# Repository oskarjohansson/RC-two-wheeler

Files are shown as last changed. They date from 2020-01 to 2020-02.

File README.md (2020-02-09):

# RC two wheeler
A 4 kW RC car with overkill BLDC motors and two VESCs and a 5 kW LiPo.  

## Hardware
- Flipsky VESC v4.12 x 2
- KEDA 63-64 190KV 2kW x 2
- Arduino Nano x2
- nRF24 x2
- 3S 60C 4000 mAh Turnigy Heavy duty LiPo
- Joystick 
- ~~2P2S N.E.S.E module x 2~~
- ~~Samsung 25E á 20A x 8~~
- ~~FrSky transmitter~~
- ~~RF Reciever~~

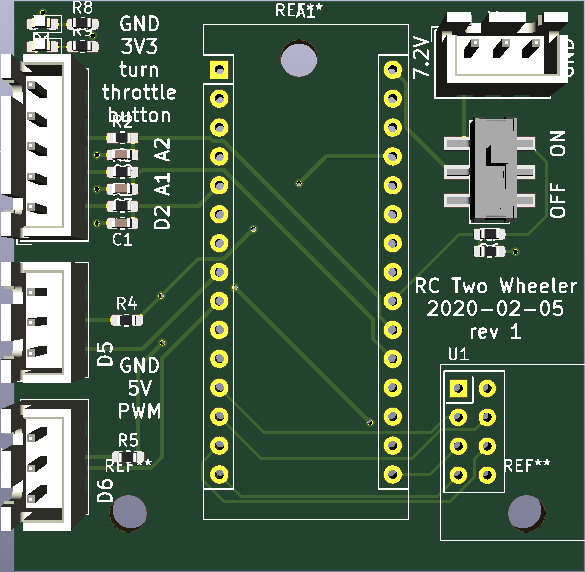
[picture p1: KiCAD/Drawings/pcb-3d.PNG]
PCB in 3D Rev 1 2020-02-09


### PCB
- PWM/5V/GND in
- Nano
- nRF24 
- ON/OFF
- Battery
- Joystick  

## Software
- VESC Tool v0.95. 
- VSCode project for Nano.

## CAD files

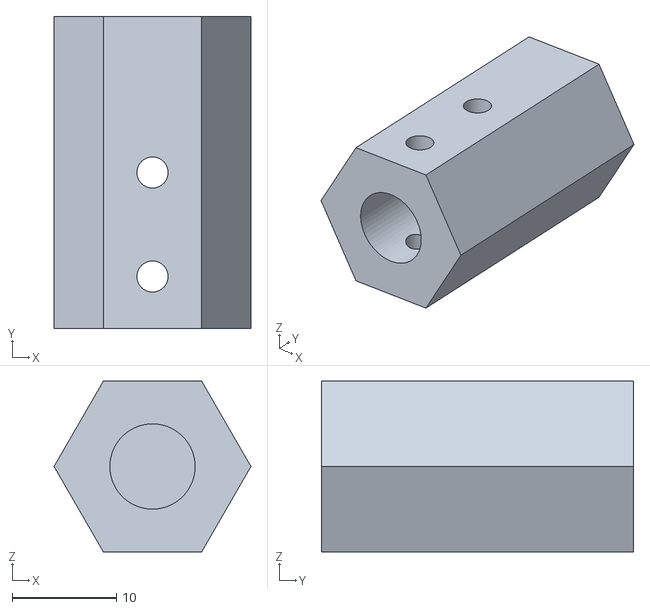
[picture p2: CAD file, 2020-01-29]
CAD/WheelInner.stl
18.9 x 30.0 x 16.4

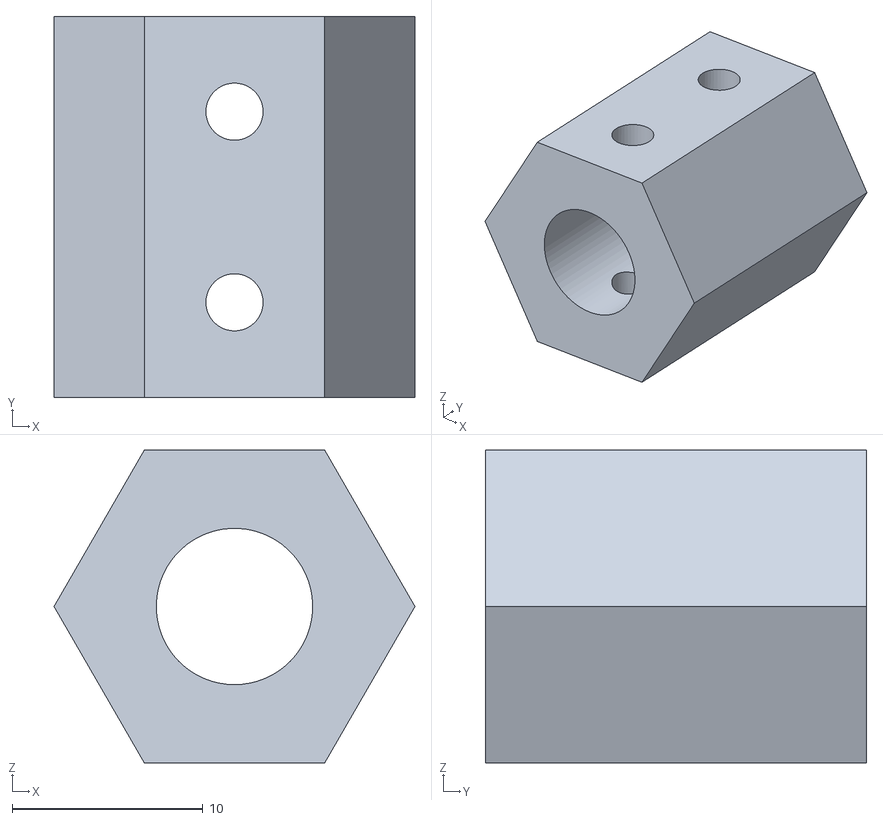
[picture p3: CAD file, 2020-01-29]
CAD/Wheel2.stl
18.9 x 20.0 x 16.4

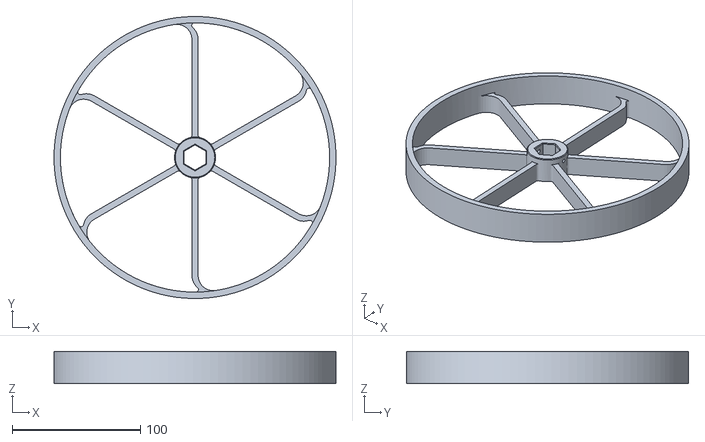
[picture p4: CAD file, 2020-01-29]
CAD/WheelOuter.stl
220.0 x 220.0 x 25.0

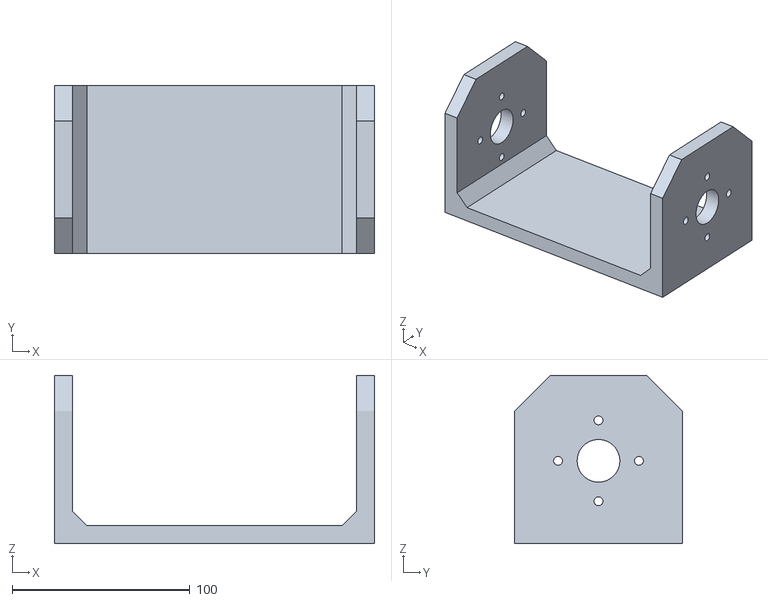
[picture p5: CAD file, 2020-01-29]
CAD/Platform.stl
180.0 x 94.5 x 94.5

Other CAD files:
CAD/Battery.ipt
CAD/KEDA_6364.ipt
CAD/NESE 2S2P.ipt
CAD/Platform.ipt
CAD/Platform.newVer.ipt
CAD/RC Assembly.iam
CAD/Wheel.ipt
CAD/Wheel2.ipt

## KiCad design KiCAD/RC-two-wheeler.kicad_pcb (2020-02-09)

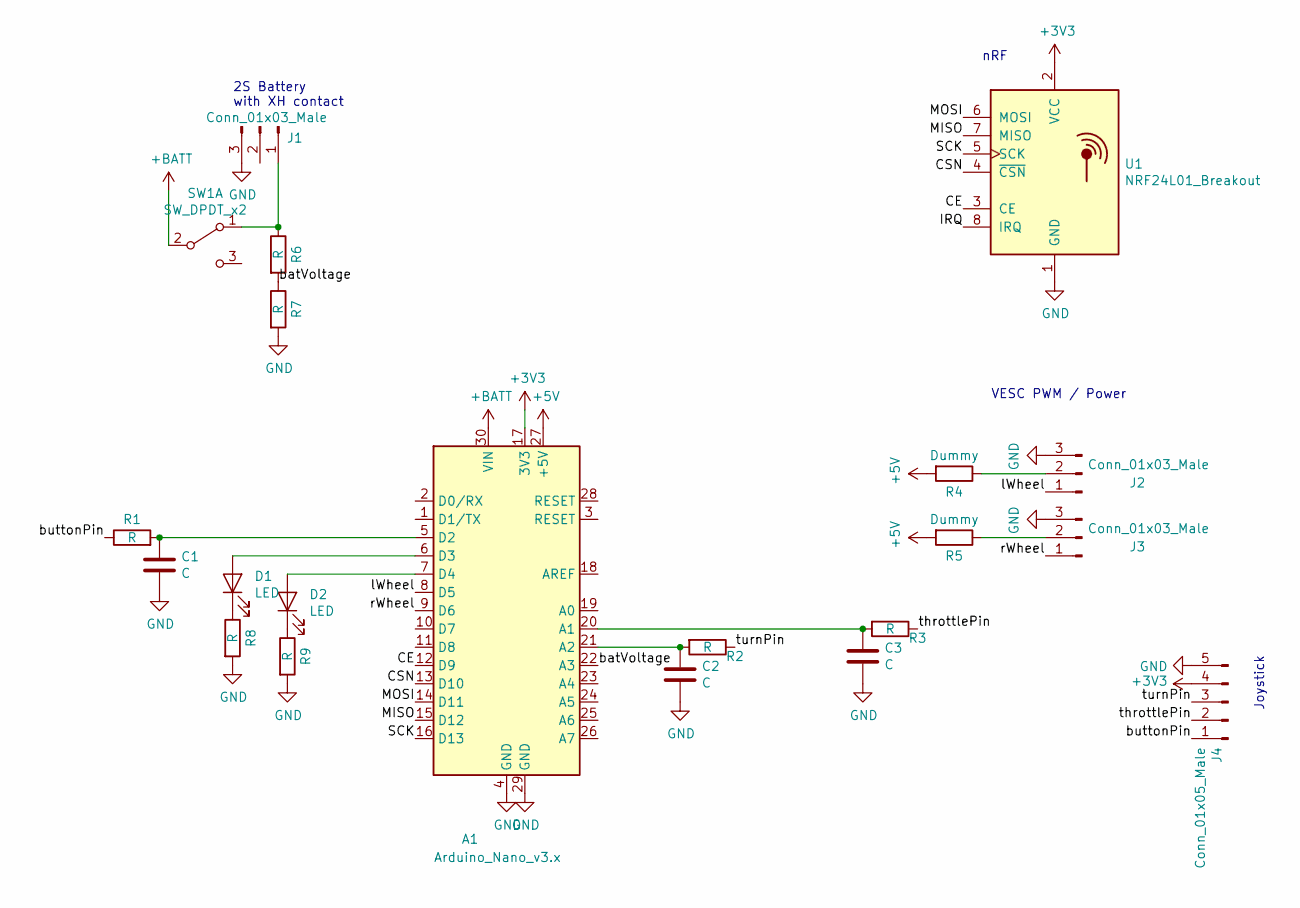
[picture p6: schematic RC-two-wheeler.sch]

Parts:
A1: Arduino_Nano_v3.x; Arduino_Nano
C1, C2, C3: C; C_0603_1608Metric_Pad1.05x0.95mm_HandSolder
D1, D2: LED; LED_0603_1608Metric_Pad1.05x0.95mm_HandSolder
J1, J2, J3: Conn_01x03_Male; JST_XH_B3B-XH-A_1x03_P2.50mm_Vertical
J4: Conn_01x05_Male; JST_XH_B5B-XH-A_1x05_P2.50mm_Vertical
R1, R2, R3, R6, R7, R8, R9: R; R_0603_1608Metric_Pad1.05x0.95mm_HandSolder
R4, R5: Dummy; R_0603_1608Metric_Pad1.05x0.95mm_HandSolder
SW1: SW_DPDT_x2; JS202011SCQN
U1: NRF24L01_Breakout; nRF24L01_Breakout

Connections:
+3V3: A1.17 (3V3), J4.4, U1.2 (VCC)
+5V: A1.27 (+5V), R4.2, R5.2
+BATT: A1.30 (VIN), SW1.2 (B)
/CE: A1.12 (D9), U1.3 (CE)
/CSN: A1.13 (D10), U1.4 (~CSN)
/IRQ: U1.8 (IRQ)
/MISO: A1.15 (D12), U1.7 (MISO)
/MOSI: A1.14 (D11), U1.6 (MOSI)
/SCK: A1.16 (D13), U1.5 (SCK)
/batVoltage: A1.22 (A3), R6.2, R7.1
/buttonPin: J4.1, R1.1
/lWheel: A1.8 (D5), J2.1
/rWheel: A1.9 (D6), J3.1
/throttlePin: J4.2, R3.1
/turnPin: J4.3, R2.1
GND: A1.4 (GND), A1.29 (GND), C1.2, C2.2, C3.2, J1.3, J2.3, J3.3, J4.5, R7.2, R8.2, R9.2, U1.1 (GND)
unnamed: A1.5 (D2), C1.1, R1.2
unnamed: A1.6 (D3), D1.2 (A)
unnamed: A1.7 (D4), D2.2 (A)
unnamed: A1.20 (A1), C3.1, R3.2
unnamed: A1.21 (A2), C2.1, R2.2
unnamed: D1.1 (K), R8.1
unnamed: D2.1 (K), R9.1
unnamed: J1.1, R6.1, SW1.1 (A)
unnamed: J2.2, R4.1
unnamed: J3.2, R5.1

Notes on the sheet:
VESC PWM / Power
Joystick
2S Battery with XH contact
nRF

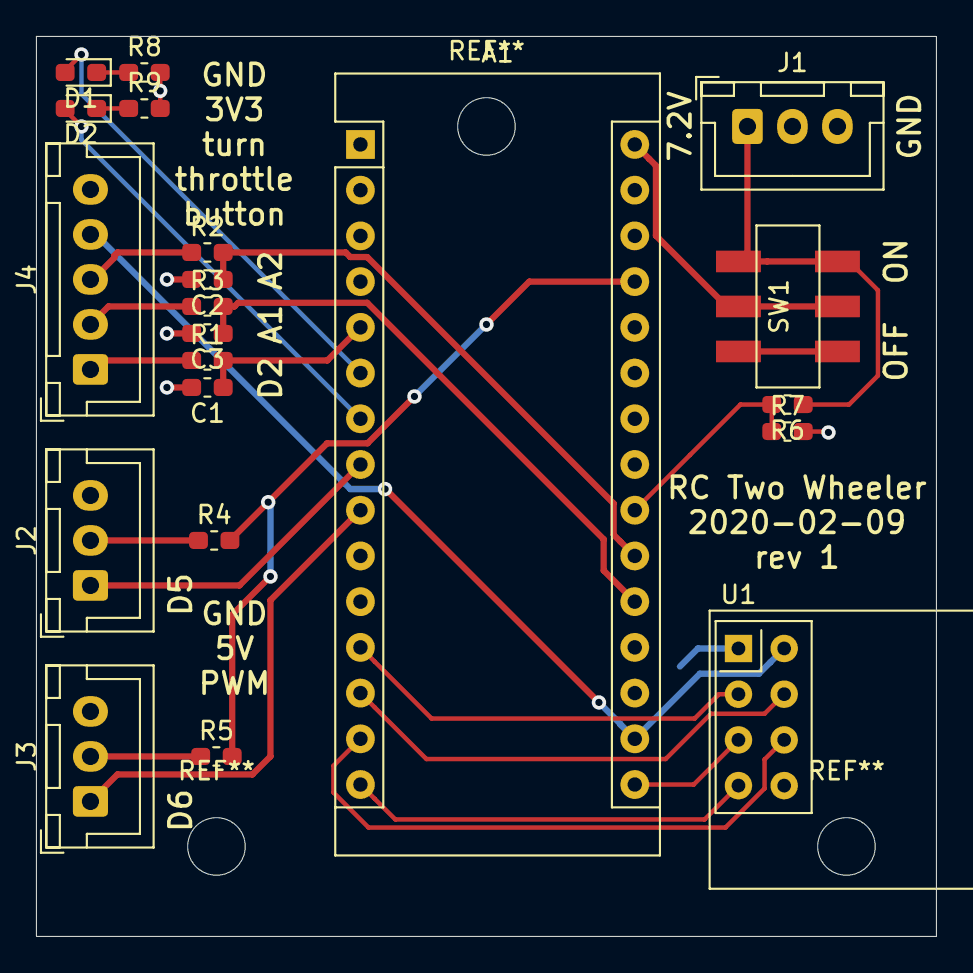
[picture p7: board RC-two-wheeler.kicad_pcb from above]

Board: 2 copper layers, 50.0 x 50.0 mm, 21 parts (0 on the bottom side), 25 nets.

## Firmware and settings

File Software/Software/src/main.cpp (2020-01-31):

/**
 * @file main.cpp
 * @author Oskar Johansson (oskar@irisnet.se)
 * @brief This project is to work with 2 MCU and 2 nRF24 to communicate throttle and turn. Based on 
 *        https://github.com/caselabbet/case-rc-car by Isak Åslund. 
 * @version 0.1
 * @date 2020-01-29 
 */
#include <Arduino.h>
#include <SoftwareSerial.h>
#include <Servo.h>
#include <RF24.h>


// Choose which to compile for 
#define reciever
//#define transmitter 
#define DEBUG

/**
 * To reuse same code for reciever and trasmitter 
 */


/**
 * Pin definition, same for reciever as transmitter
 */
#define lWheelPin 5
#define rWheelPin 6
#define throttlePin A1
#define turnPin A2
#define CE 9 
#define CSN 10

RF24 radio(CE,CSN); 
const byte address[6] = "00010";    // Adress for communicating
unsigned long lastData = 0;         // Used for knowing if data has been received recently
unsigned long lasttime = millis();  // To track of how long time since last transmitt / recieve 
int throttleComp = 0; 
int turnComp = 0;
bool setupOk = false; 
/**
 * A struct to store the recieved 
 * throttle and turn  
 */
typedef struct{
    int throttle;
    int turn;
}message_t;                         // Struct for making sending/receiving easy
message_t msg;
message_t analog; 
/**
 * Create the wheels 
 */
Servo lWheel, rWheel;

#define NOSPEED 90            // In servo degree
#define DEFAULTSPEED 20       // In servo degree
#define MAXSPEED 45           // In servo degree
#define MAXTURN 20            // In servo degree 
#define MAX_TIMEOUT 500       // in ms


/**
 * @brief Reciever:   Write the throttle and turn to the 
 *                    left and right wheel. Also checks
 *                    if the input values are to high/low. 
 *                    A turn is simply throttle+-turn on
 *                    this two-wheeler. 
 * 
 * @param throttle  - The throttle 0 - 180 
 * @param turn      - The turn 0 - 180
 */
void writeToWheels(int throttle, int turn) {
  int lSpeed = NOSPEED; int rSpeed = NOSPEED; 
  // 0 is max, 90 is still, 180 max reverse
  if(throttle < MAXSPEED)
    throttle = MAXSPEED; 
  else if (throttle > (MAXSPEED+90))
    throttle = MAXSPEED+90; 
  
  // Check so the turn speed isn't to fast 
  if(turn < MAXTURN)
    turn = MAXTURN;
  else if (turn > MAXTURN+90)
    turn = MAXTURN + 90; 
  // 
  turn -= 90; 
  // To check if it wasn't to long ago the input was recieved 
  if((millis() - lasttime)< MAX_TIMEOUT) {
    lSpeed = throttle+turn/2; 
    rSpeed = throttle-turn/2; 
  }
  
  // Write to output
  lWheel.write(lSpeed);
  rWheel.write(rSpeed);
  
  #ifdef DEBUG
      Serial.print("Input throttle: "); Serial.print(throttle); Serial.print("\t input turn: "); Serial.println(turn);
      Serial.print("Left output: "); Serial.print(lSpeed); Serial.print("\t \t Right output: "); Serial.println(rSpeed);
  #endif 
}

/**
 * @brief Transmitter:  Convert analog in signal to a throttle
 *                      level and write to nRF. 
 * 
 * @return true   - If successful transmitt
 * @return false  - If fail in writing to nRF
 */
bool writeToRadio() {
    // Convert to a servo signal (0 - 180 degrees) 90 is still, 0 max, 180 max
    msg.throttle = analog.throttle * 180.0 / 1024.0; 
    msg.turn = analog.turn * 180.0 / 1024.0; 
    bool succ = radio.write(&msg,sizeof(msg));
    #ifdef DEBUG
      Serial.print("Sent throttle: "); Serial.print(msg.throttle); Serial.print("\t sent turn: "); Serial.print(msg.turn); Serial.print(" successful transmitt: "); Serial.println(succ);
    #endif 
    return succ; 
}

/**
 * @brief Transmitter:  Write to nRF the throttle and turn. 
 *        Reciever:     Write the input from nRF to servo.  
 */
void writeOutput() {
  #ifdef transmitter
    writeToRadio(); 
  #else 
      writeToWheels(msg.throttle, msg.turn); 
  #endif
}


/**
 * @brief Transmitter:  Reads the analog value from joystick.
 *        Reciever:     See if new data available on nRF and 
 *                      save it to msg.  
 */
void readInput() {
  #ifdef transmitter 
    // Read the analog input with a simple LP filter
    analog.throttle = (analog.throttle + (analogRead(throttlePin)+throttleComp))/2;
    analog.turn = (analog.turn + (analogRead(turnPin)+turnComp))/2;
    #ifdef DEBUG
      Serial.print("Read throttle: "); Serial.print(analog.throttle); Serial.print("\t read turn: "); Serial.println(analog.turn);
    #endif 
  #else
    #ifdef DEBUG
      Serial.print("Radio available: "); Serial.println(radio.available());
    #endif 
    if(radio.available()) {
      radio.read(&msg, sizeof(msg)); 
      lasttime = millis(); 
      #ifdef DEBUG
        Serial.println("Recieved new input!");
      #endif
    } 
  #endif
}


/**
 * @brief Setup module as transmitter and sets analog input from joystick. 
 *        Also compensate for joystick value. Sets current value as new 0. 
 * 
 * @return true  - If able to connect setup nRF module
 * @return false - If unable to connect and setup nRf module
 */
bool setupTransmitter() {
  // Analog read for throttle and turn value
  pinMode(throttlePin, INPUT);
  pinMode(turnPin, INPUT);
  
  // To compensate for bad joystick
  // sets the current value as "middle" value. 
  throttleComp = 512 - analogRead(throttlePin);
  turnComp = 512 - analogRead(turnPin);
  
  // Start the nRF 
  if(radio.begin()) {
    #ifdef DEBUG
      Serial.println("Radio has begun!");
    #endif
  } 
  radio.openWritingPipe(address);
  radio.setPALevel(RF24_PA_MAX); 
  radio.setRetries(3,5); // delay, count
  radio.setDataRate(RF24_250KBPS);
  //radio.stopListening();
  
  // Return 1 if found nRf connected, 0 else
  return radio.isChipConnected();
}

/**
 * @brief Setup nRF module and the servo pins. 
 * 
 * @return true  - If able to connect setup nRF module
 * @return false - If unable to connect and setup nRf module
 */
bool setupReciever() {
    // Attach PWM pins for wheel signal
    lWheel.attach(lWheelPin);
    rWheel.attach(rWheelPin);
    // Write 90 deg (zero in speed)
    lWheel.write(NOSPEED);
    rWheel.write(NOSPEED);
    msg.throttle = NOSPEED;
    msg.turn = NOSPEED; 

    // Start the nRf 
    radio.begin();
    radio.openReadingPipe(1, address);
    //radio.setPALevel(RF24_PA_MAX);
    radio.setDataRate(RF24_250KBPS);
    radio.startListening();

    // Return 1 if found nRf connected, 0 else
    return radio.isChipConnected();
}


void setup() {
  #ifdef DEBUG
  Serial.begin(9600);
  #endif 


  #ifdef transmitter 
    setupOk = setupTransmitter(); 
  #else 
    setupOk = setupReciever();
  #endif 
}

void loop() {
  readInput(); 
  writeOutput();
}

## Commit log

2019-05-20 Create part, not finished
    Not finished
    [KEDA_6364.ipt]
2019-05-20 Create NESE 2S2P.ipt
    [NESE 2S2P.ipt]
2019-05-20 Create RC Assembly.iam
    [RC Assembly.iam]
2019-05-20 Just update
    [NESE 2S2P.ipt, Platform.ipt, Platform.stl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]
2019-05-20 First draft
    [Platform.ipt, Wheel.ipt, parameters.xlsx]
2019-05-23 Updated wheel and made it two seperated
    [Wheel.ipt, parameters.xlsx]
2019-07-09 Added servo lib
2019-07-09 Workning firmware
    The firmware is now working with BT-device and Car bluetooth app on android
2019-07-09 Updated design
    [Battery.ipt, Platform.ipt, Wheel.ipt]
2020-01-29 Added wheels
    [Platform.stl, Wheel2.ipt, Wheel2.stl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]
2020-01-31 Changed to latest hardware components
    Now using two Arduino Nano with nRF24 to communicate instead of a real transmitter.
2020-02-03 Created a KiCAD project
    [RC-two-wheeler.kicad_pcb, RC-two-wheeler.sch]
2020-02-05 Routed the board, must double check LiPo con!
    [RC-two-wheeler.kicad_pcb, RC-two-wheeler.sch]
2020-02-09 Added 2 led and made DRC
    [RC-two-wheeler.kicad_pcb, RC-two-wheeler.sch]
2020-02-09 Updated rev date to 20200209
    [RC-two-wheeler.kicad_pcb]
2020-02-09 Generate gerber files and order
